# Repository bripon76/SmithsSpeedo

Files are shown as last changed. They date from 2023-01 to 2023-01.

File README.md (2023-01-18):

# SmithsSpeedo
 DIY Speedo Conversation from mechanical to electical

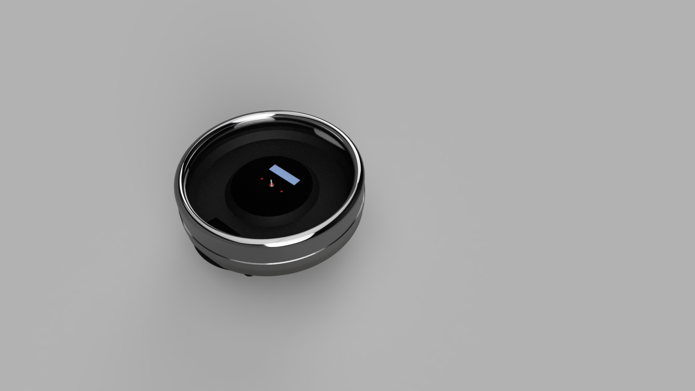
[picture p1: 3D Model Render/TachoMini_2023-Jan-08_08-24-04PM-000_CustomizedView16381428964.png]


# ToDo

- Control and order Top PCB
- Complete, control and order Bottom PCB
- modify Atmel Code for speaking with ESP32 Code

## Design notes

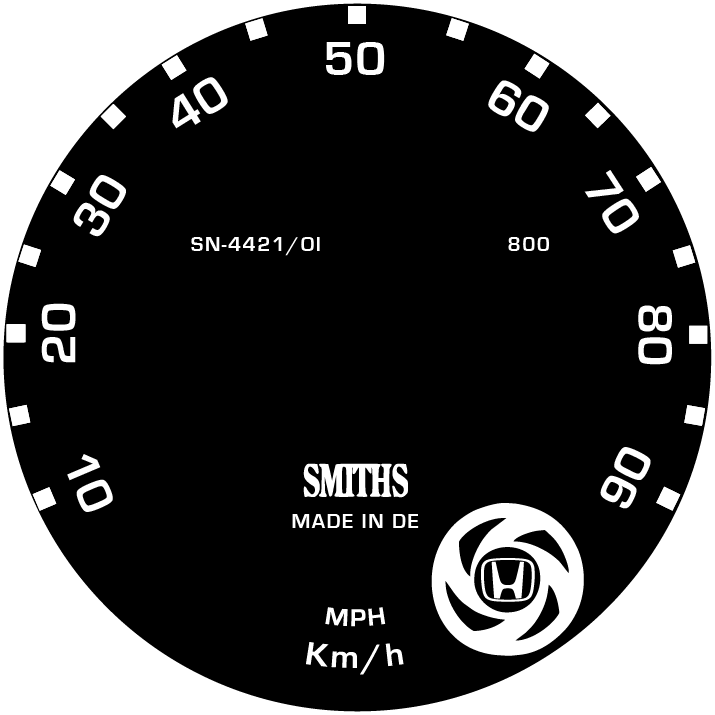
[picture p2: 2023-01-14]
Tachoscheiben/Tachoscheibe HondaMini.png

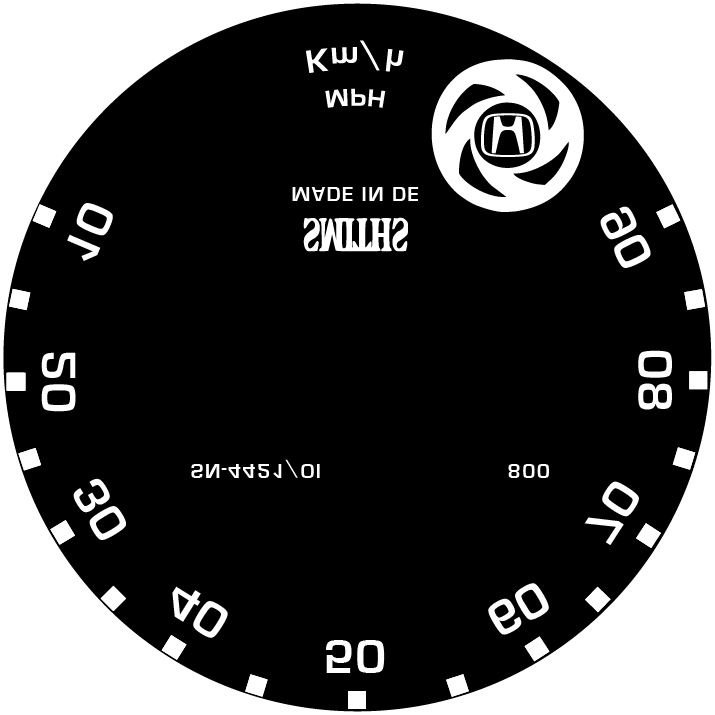
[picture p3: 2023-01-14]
Tachoscheiben/Tachoscheibe HondaMini_flipped.png

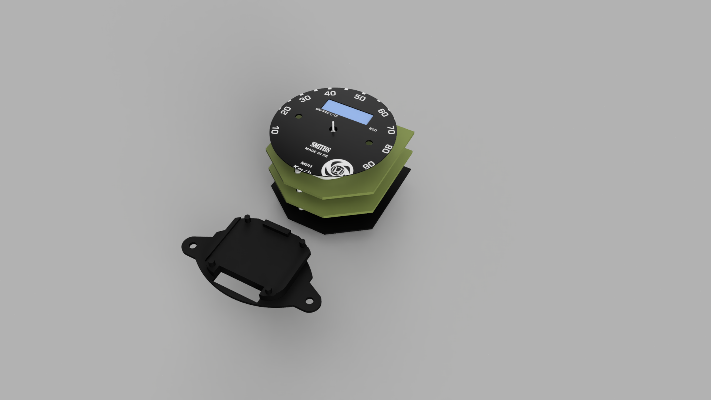
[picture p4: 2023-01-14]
3D Model Render/TachoMini_2022-Apr-28_12-24-32PM-000_CustomizedView3400404055.png

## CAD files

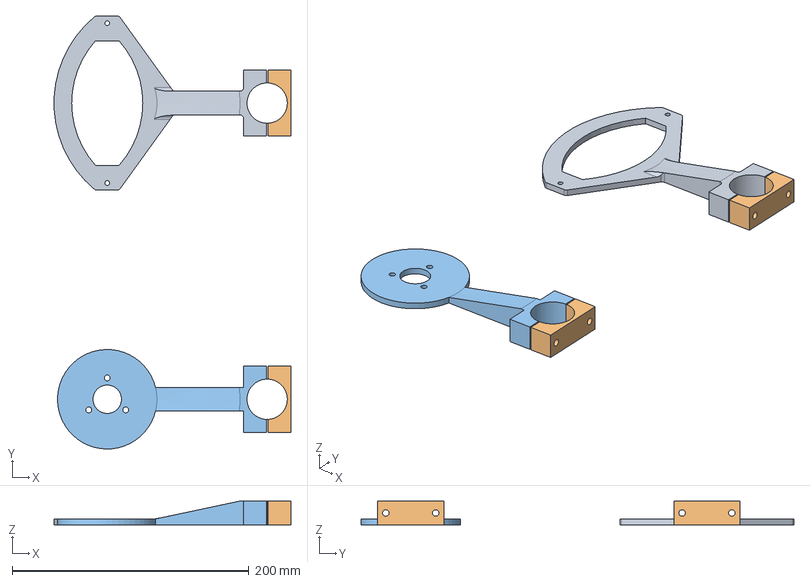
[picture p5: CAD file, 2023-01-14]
3D Model Render/TempHalter v3.step
199.8 x 365.5 x 20.0 mm
Halter Raingauge
Klammer Raingauge
Halter TEMP/HUM
Klammer Tem/HUM

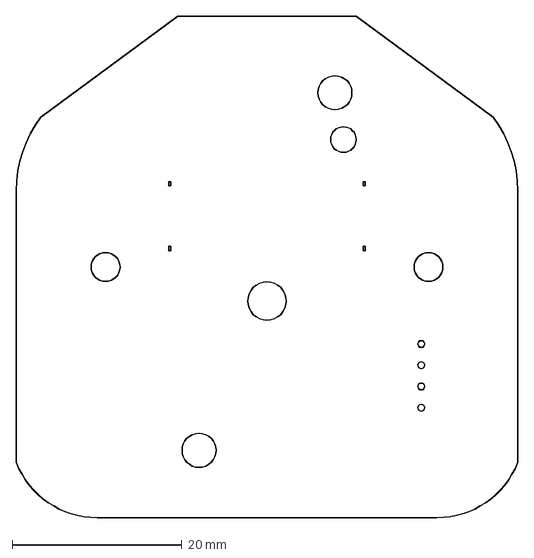
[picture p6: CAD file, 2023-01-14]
PCB Cut.dxf
59.0 x 59.0 mm

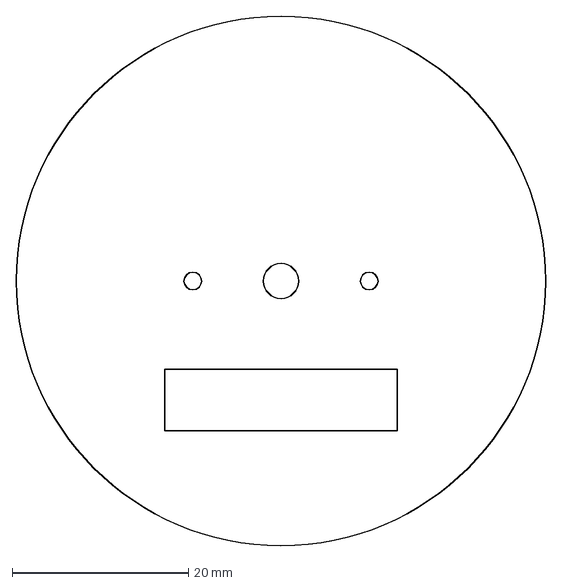
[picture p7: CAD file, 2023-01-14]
PCBs/Tacho Blende/Blende PCB.dxf
60.0 x 60.0 mm

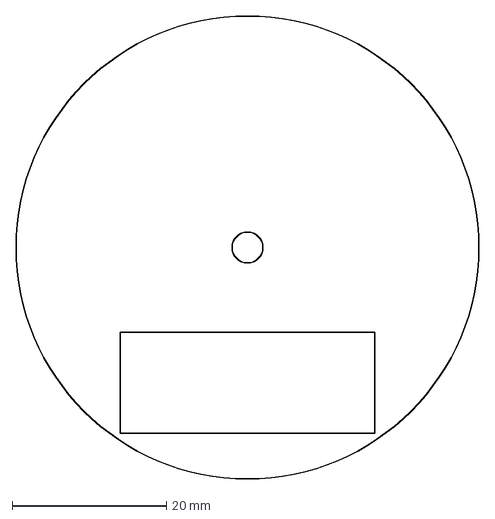
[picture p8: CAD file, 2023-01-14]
Tachoscheiben/Tachoscheibe.dxf
60.0 x 60.0 mm

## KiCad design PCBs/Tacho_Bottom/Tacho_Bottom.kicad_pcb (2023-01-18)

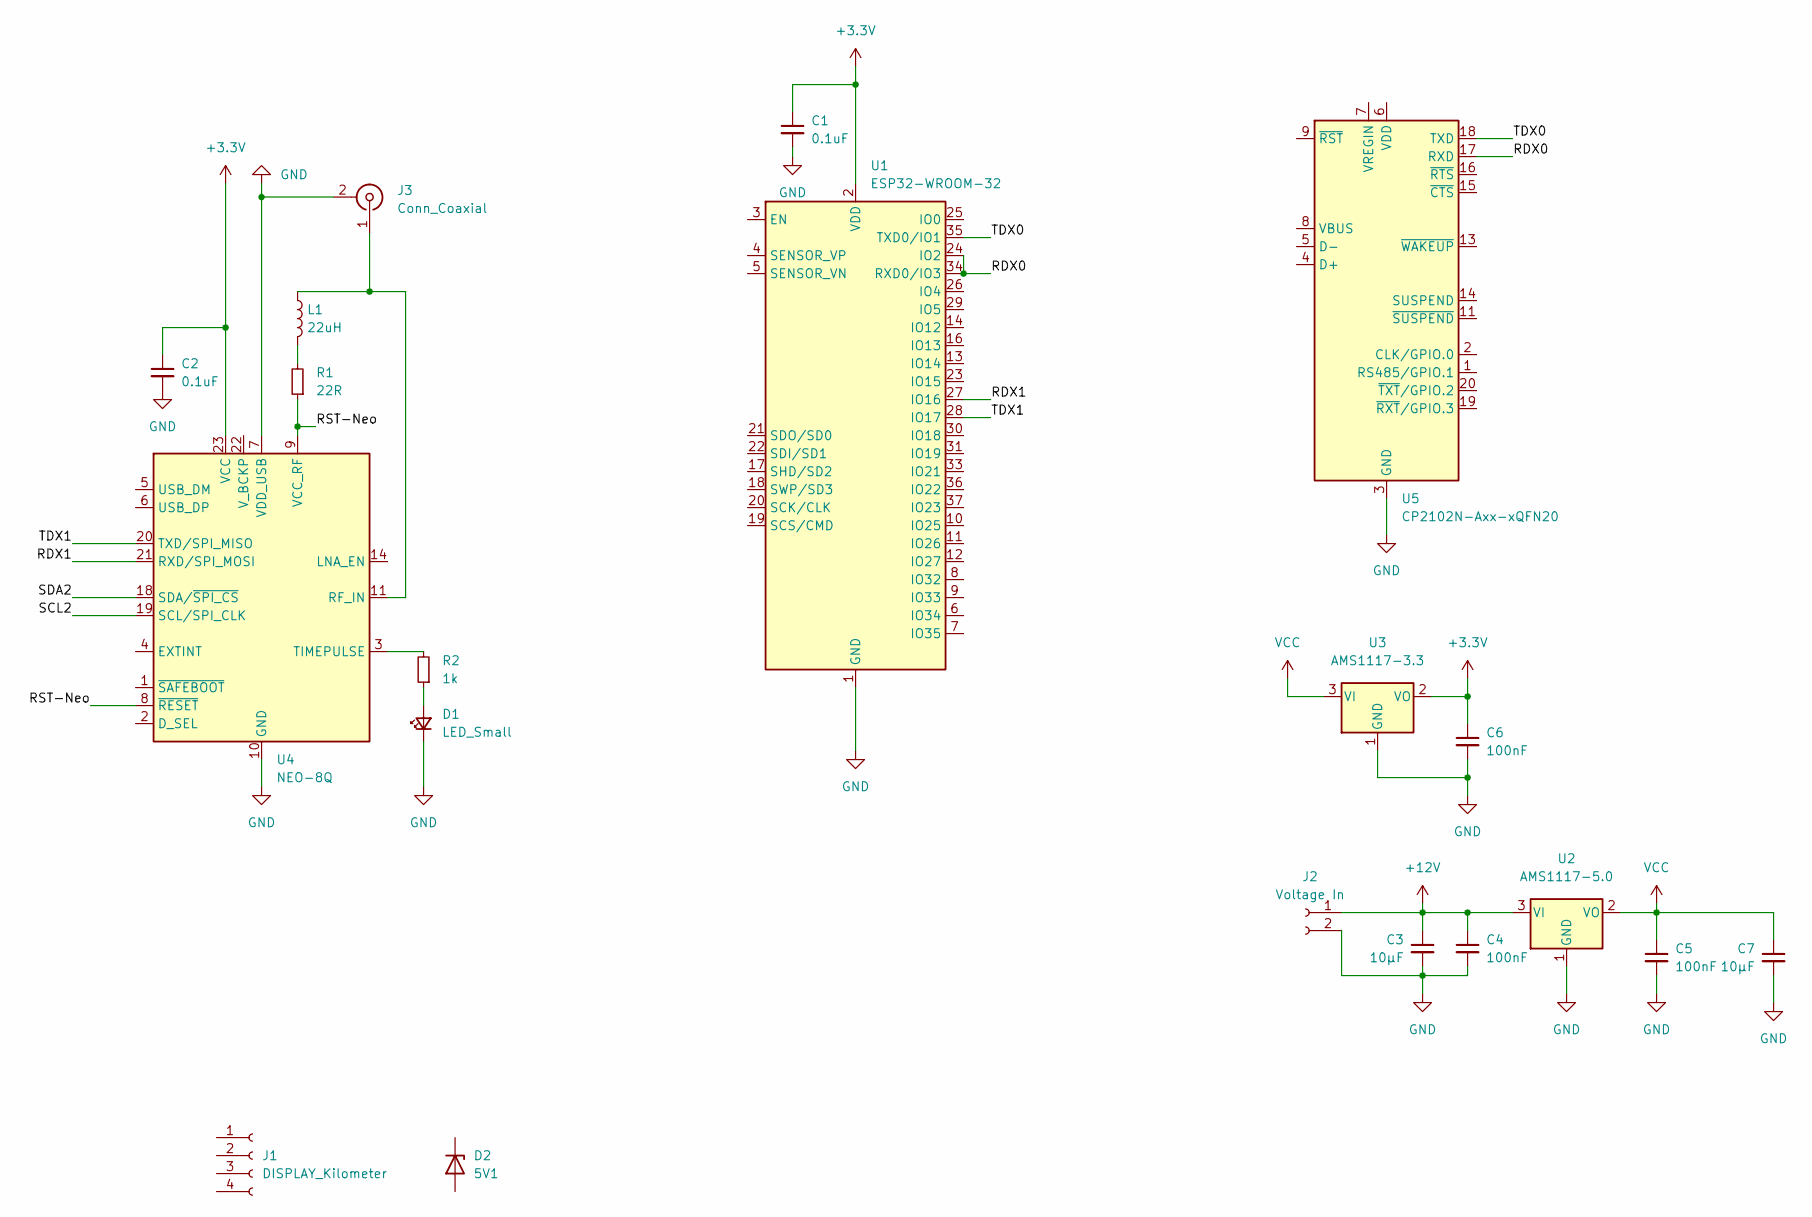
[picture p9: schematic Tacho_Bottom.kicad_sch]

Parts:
C1, C2: 0.1uF; C_0603_1608Metric_Pad1.08x0.95mm_HandSolder
C3, C7: 10µF; C_0805_2012Metric_Pad1.18x1.45mm_HandSolder
C4, C5, C6: 100nF; C_0603_1608Metric_Pad1.08x0.95mm_HandSolder
D1: LED_Small; LED_1206_3216Metric_Pad1.42x1.75mm_HandSolder
D2: 5V1; D_SOD-123
J1: DISPLAY_Kilometer; PinHeader_1x04_P2.54mm_Vertical
J2: Voltage In; SolderWire-0.5sqmm_1x02_P4.8mm_D0.9mm_OD2.3mm
J3: Conn_Coaxial; U.FL_Molex_MCRF_73412-0110_Vertical
L1: 22uH; L_12x12mm_H8mm
R1: 22R; R_0603_1608Metric_Pad0.98x0.95mm_HandSolder
R2: 1k; R_0603_1608Metric_Pad0.98x0.95mm_HandSolder
U1: ESP32-WROOM-32
U2: AMS1117-5.0; SOT-223-3_TabPin2
U3: AMS1117-3.3; SOT-223-3_TabPin2
U4: NEO-8Q; ublox_NEO
U5: CP2102N-Axx-xQFN20; SiliconLabs_QFN-20-1EP_3x3mm_P0.5mm

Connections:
+3.3V: C1.1, C2.1, C6.1, U1.2 (VDD), U3.2 (VO), U4.23 (VCC)
+12V: C3.1, C4.1, J2.1, U2.3 (VI)
/RDX0: U1.24 (IO2), U1.34 (RXD0/IO3), U5.17 (RXD)
/RDX1: U1.27 (IO16), U4.21 (RXD/SPI_MOSI)
/RST-Neo: R1.1, U4.8 (~RESET), U4.9 (VCC_RF)
/SCL2: U4.19 (SCL/SPI_CLK)
/SDA2: U4.18 (SDA/~SPI_CS)
/TDX0: U1.35 (TXD0/IO1), U5.18 (TXD)
/TDX1: U1.28 (IO17), U4.20 (TXD/SPI_MISO)
GND: C1.2, C2.2, C3.2, C4.2, C5.2, C6.2, C7.2, D1.1 (K), J2.2, J3.2 (Ext), U1.1 (GND), U1.15 (GND), U1.38 (GND), U1.39 (GND), U2.1 (GND), U3.1 (GND), U4.7 (VDD_USB), U4.10 (GND), U4.12 (GND), U4.13 (GND), U4.24 (GND), U5.3 (GND), U5.12 (GND), U5.21 (GND)
unnamed: D1.2 (A), R2.1
unnamed: J3.1 (In), L1.1, U4.11 (RF_IN)
unnamed: L1.2, R1.2
unnamed: R2.2, U4.3 (TIMEPULSE)
VCC: C5.1, C7.1, U2.2 (VO), U3.3 (VI)

Board: 2 copper layers, 19 parts (2 on the bottom side), 12 nets, no tracks yet.

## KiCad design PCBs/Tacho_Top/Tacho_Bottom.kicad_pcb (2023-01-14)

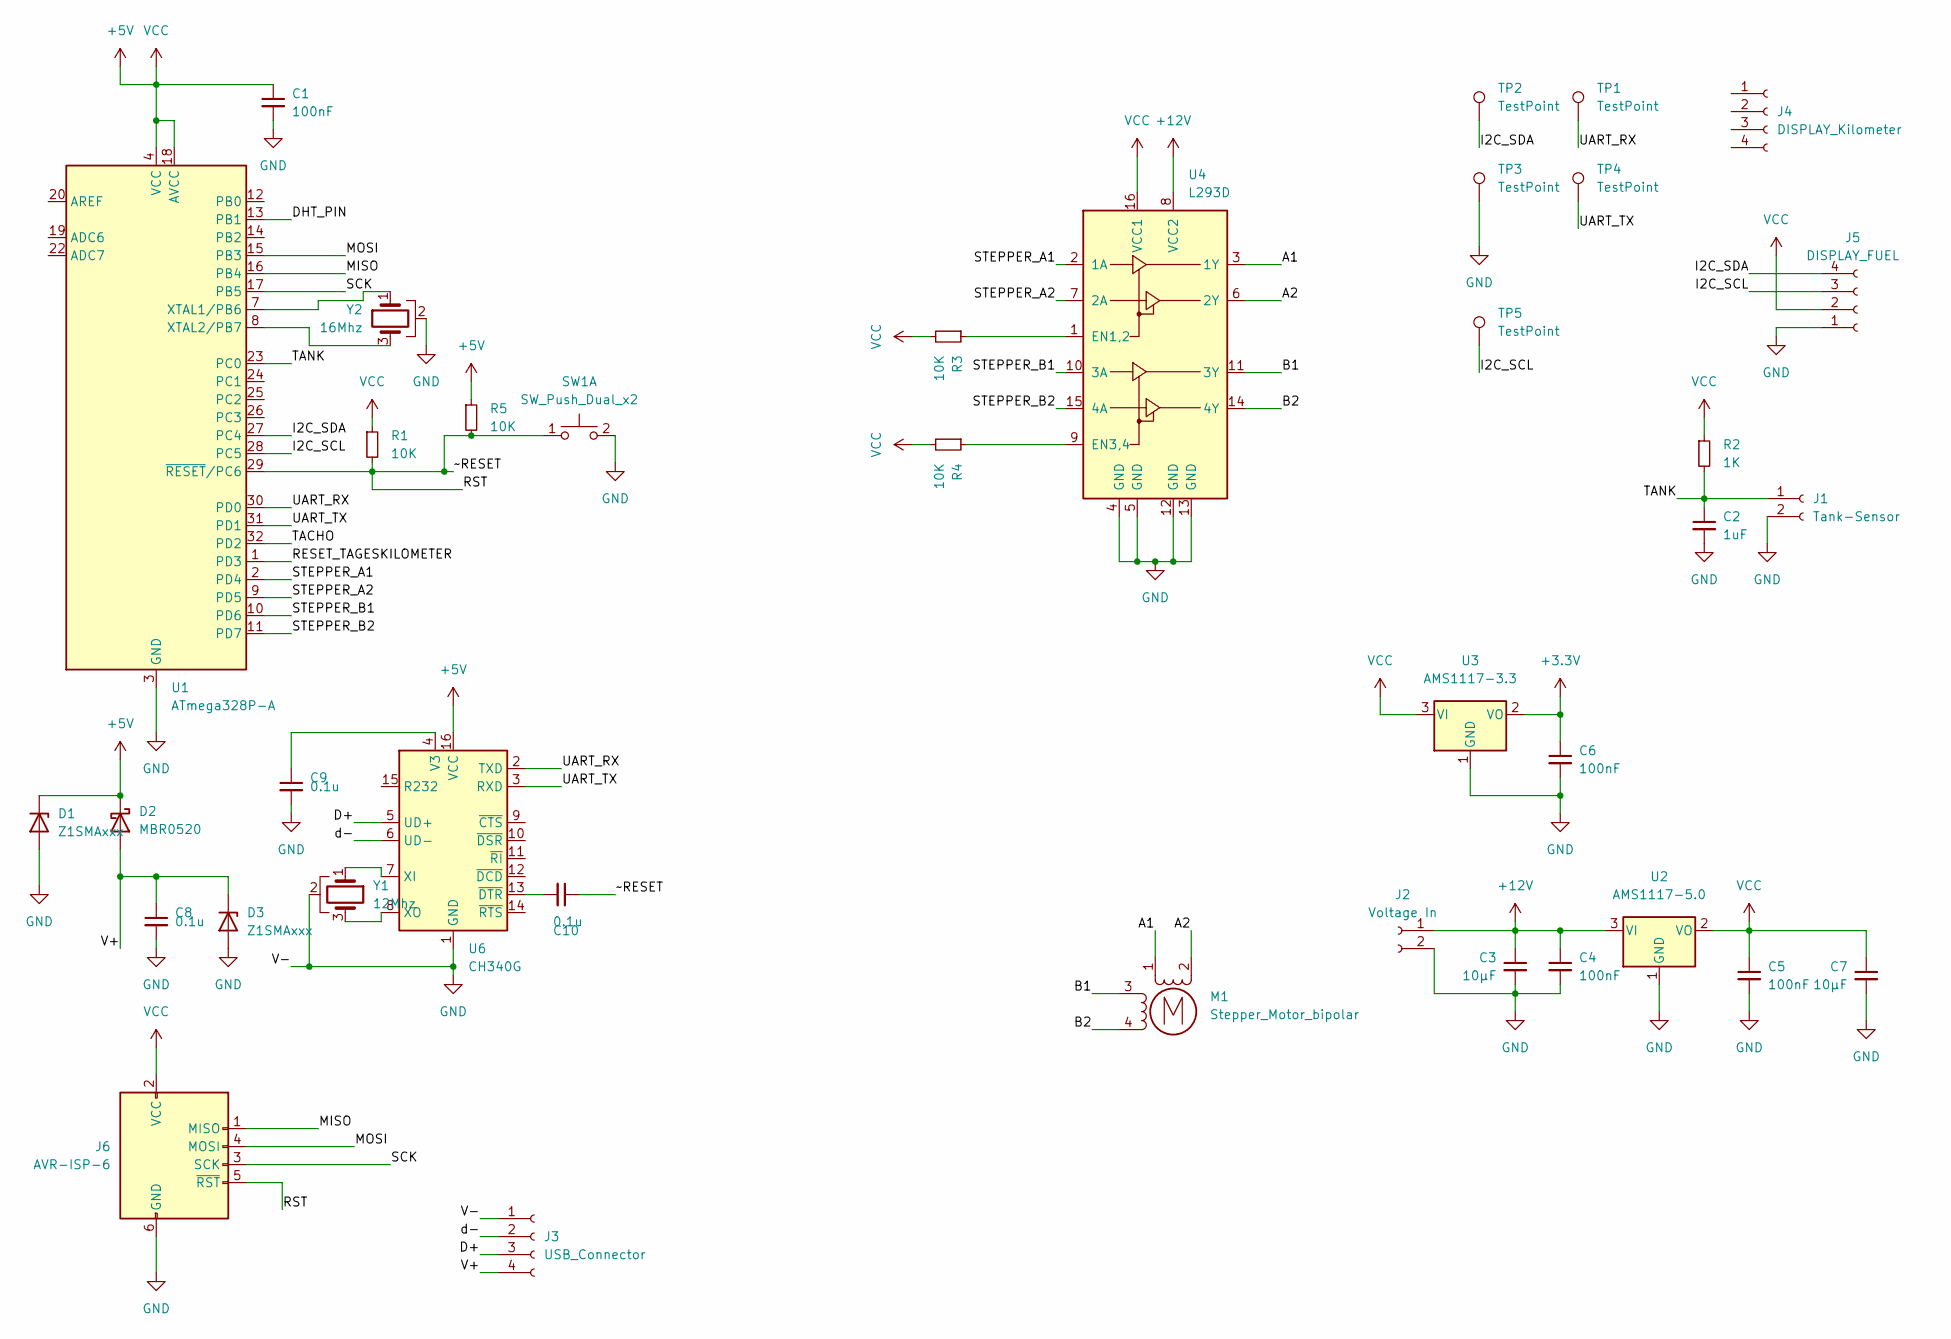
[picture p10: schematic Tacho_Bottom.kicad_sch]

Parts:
C1, C4, C5, C6: 100nF; C_0603_1608Metric_Pad1.08x0.95mm_HandSolder
C2: 1uF; R_0603_1608Metric_Pad0.98x0.95mm_HandSolder
C3, C7: 10µF; C_0805_2012Metric_Pad1.18x1.45mm_HandSolder
C8, C9, C10: 0.1u; R_0603_1608Metric_Pad0.98x0.95mm_HandSolder
D1, D3: Z1SMAxxx; D_SMA
D2: MBR0520; D_SOD-123
J1: Tank-Sensor; SolderWire-0.1sqmm_1x02_P3.6mm_D0.4mm_OD1mm
J2: Voltage In; SolderWire-0.5sqmm_1x02_P4.8mm_D0.9mm_OD2.3mm
J3: USB_Connector; PinHeader_1x04_P2.54mm_Vertical
J4: DISPLAY_Kilometer; PinHeader_1x04_P2.54mm_Vertical
J5: DISPLAY_FUEL; SolderWire-0.1sqmm_1x04_P3.6mm_D0.4mm_OD1mm
J6: AVR-ISP-6; PinHeader_2x03_P2.54mm_Vertical
M1: Stepper_Motor_bipolar; X27-168
R1, R3, R4, R5: 10K; R_0603_1608Metric_Pad0.98x0.95mm_HandSolder
R2: 1K; R_0603_1608Metric_Pad0.98x0.95mm_HandSolder
SW1: SW_Push_Dual_x2
TP1, TP2, TP3, TP4, TP5: TestPoint; TestPoint_Pad_D2.0mm
U1: ATmega328P-A; TQFP-32_7x7mm_P0.8mm
U2: AMS1117-5.0; SOT-223-3_TabPin2
U3: AMS1117-3.3; SOT-223-3_TabPin2
U4: L293D; DIP-16_W7.62mm
U6: CH340G; SOIC-16_3.9x9.9mm_P1.27mm
Y1: 12Mhz
Y2: 16Mhz

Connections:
+3.3V: C6.1, U3.2 (VO)
+5V: C1.1, C5.1, C7.1, D1.1 (K), D2.1 (K), J5.2, J6.2 (VCC), R1.1, R2.1, R3.2, R4.2, R5.1, U1.4 (VCC), U1.6 (VCC), U1.18 (AVCC), U2.2 (VO), U3.3 (VI), U4.16 (VCC1), U6.16 (VCC)
+12V: C3.1, C4.1, J2.1, U2.3 (VI), U4.8 (VCC2)
/A1: M1.1, U4.3 (1Y)
/A2: M1.2 (-), U4.6 (2Y)
/B1: M1.3, U4.11 (3Y)
/B2: M1.4, U4.14 (4Y)
/D+: J3.3, U6.5 (UD+)
/DHT_PIN: U1.13 (PB1)
/I2C_SCL: J5.3, TP5.1, U1.28 (PC5)
/I2C_SDA: J5.4, TP2.1, U1.27 (PC4)
/MISO: J6.1 (MISO), U1.16 (PB4)
/MOSI: J6.4 (MOSI), U1.15 (PB3)
/RESET_TAGESKILOMETER: U1.1 (PD3)
/RST: C10.1, J6.5 (~RST), R1.2, R5.2, SW1.1 (C), U1.29 (~RESET/PC6)
/SCK: J6.3 (SCK), U1.17 (PB5)
/STEPPER_A1: U1.2 (PD4), U4.2 (1A)
/STEPPER_A2: U1.9 (PD5), U4.7 (2A)
/STEPPER_B1: U1.10 (PD6), U4.10 (3A)
/STEPPER_B2: U1.11 (PD7), U4.15 (4A)
/TACHO: U1.32 (PD2)
/TANK: C2.1, J1.1, R2.2, U1.23 (PC0)
/UART_RX: TP1.1, U1.30 (PD0), U6.2 (TXD)
/UART_TX: TP4.1, U1.31 (PD1), U6.3 (RXD)
/V+: C8.1, D2.2 (A), D3.1 (K), J3.4
/d-: J3.2, U6.6 (UD-)
GND: C1.2, C2.2, C3.2, C4.2, C5.2, C6.2, C7.2, C8.2, C9.2, D1.2 (A), D3.2 (A), J1.2, J2.2, J3.1, J5.1, J6.6 (GND), SW1.2 (D), TP3.1, U1.3 (GND), U1.5 (GND), U1.21 (GND), U2.1 (GND), U3.1 (GND), U4.4 (GND), U4.5 (GND), U4.12 (GND), U4.13 (GND), U6.1 (GND), Y1.2, Y2.2
unnamed: C9.1, U6.4 (V3)
unnamed: C10.2, U6.13 (~DTR)
unnamed: R3.1, U4.1 (EN1,2)
unnamed: R4.1, U4.9 (EN3,4)
unnamed: U1.7 (XTAL1/PB6), Y2.1
unnamed: U1.8 (XTAL2/PB7), Y2.3
unnamed: U6.7 (XI), Y1.1
unnamed: U6.8 (XO), Y1.3

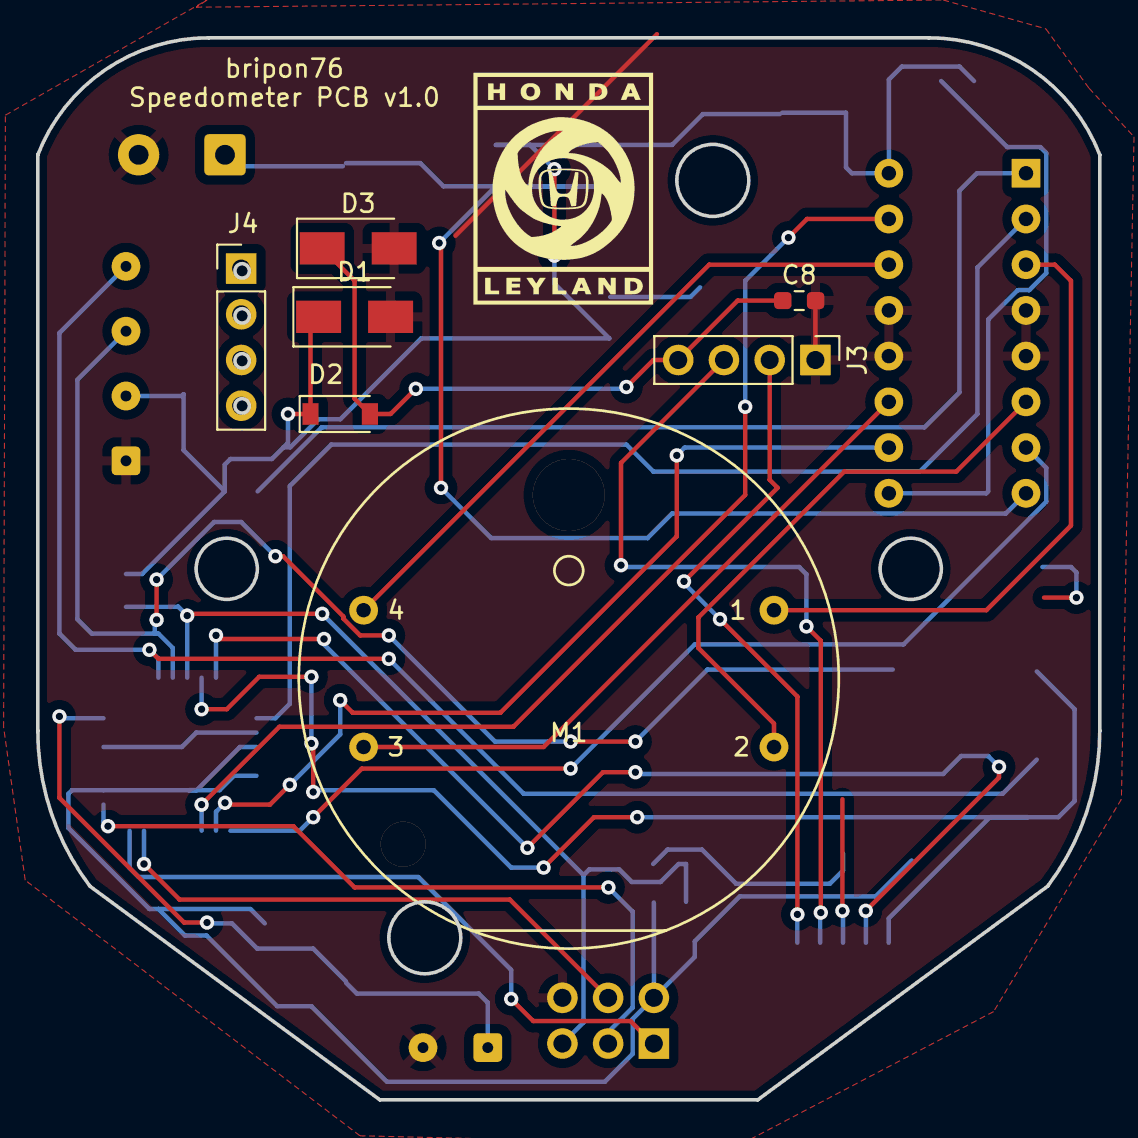
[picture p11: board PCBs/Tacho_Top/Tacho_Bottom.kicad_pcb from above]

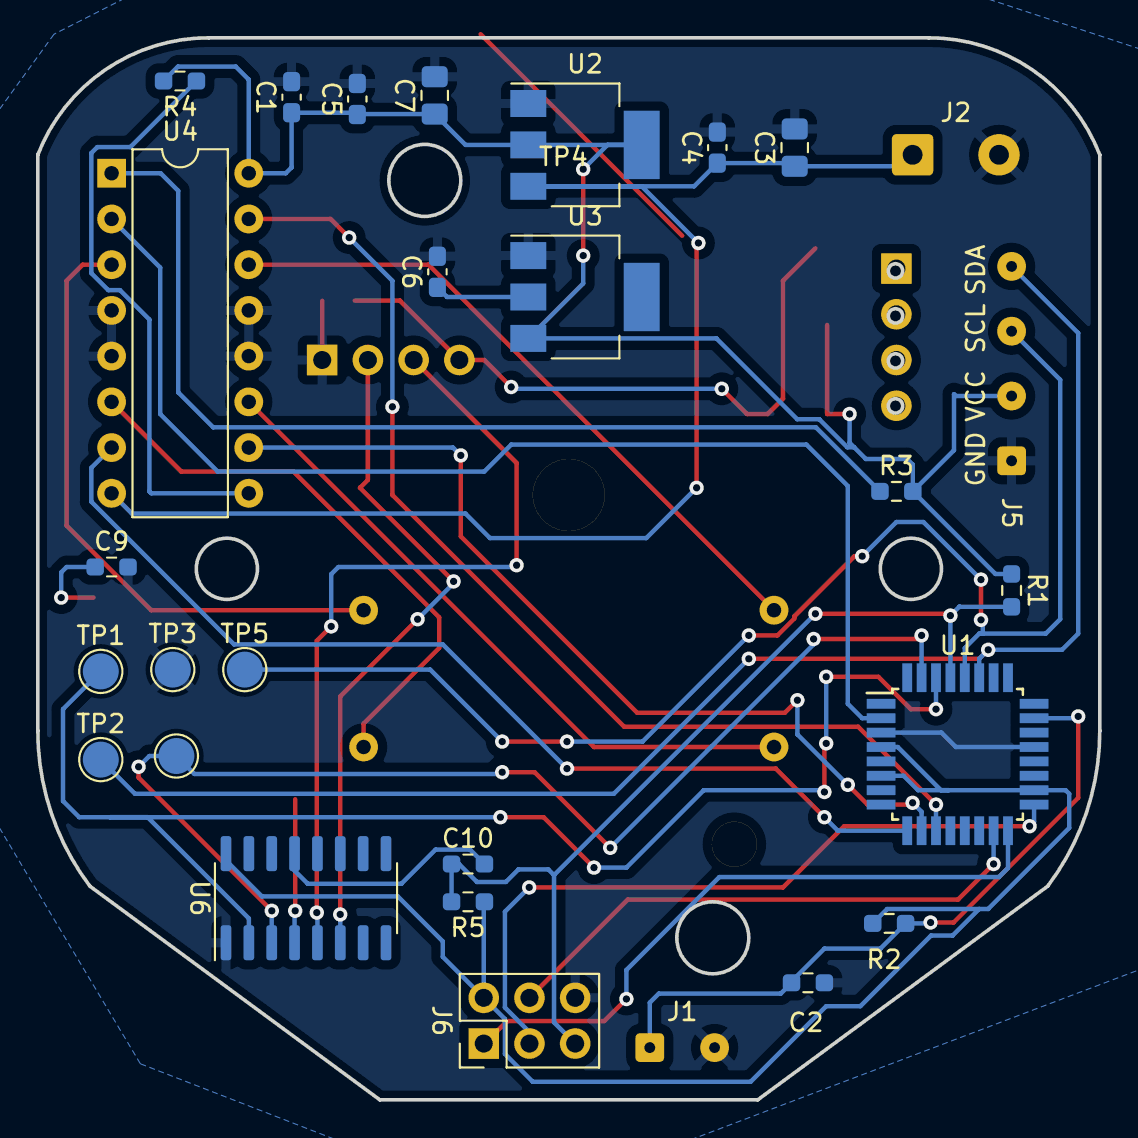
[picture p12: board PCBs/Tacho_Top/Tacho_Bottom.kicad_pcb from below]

Board: 2 copper layers, 59.0 x 59.0 mm, 35 parts (28 on the bottom side), 28 nets.

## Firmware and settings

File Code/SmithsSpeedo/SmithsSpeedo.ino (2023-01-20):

//To Do:
//Kilometer alle 10 min. speichern (optional)
//Tageskilometerzähler (Differenz zwischen realem Kilometerzähler und letztem Reset-Kilometerstand)

#include <EEPROM.h>
#include <Arduino.h>
#include <U8g2lib.h>

#ifdef U8X8_HAVE_HW_SPI
#include <SPI.h>
#endif
#ifdef U8X8_HAVE_HW_I2C
#include <Wire.h>
#endif

//Tacho-Stepper Motor
#define STEPS_KMH_140 690.0 /*Steps per 140 km/h*/
#define STEPS_MAXRANGE 850 /* Rechte Seite FUEL Ausschnitt*/
#include <SwitecX25.h>

//SoftwareSerial
#include <SoftwareSerial.h>
SoftwareSerial mySerial(2, 3); // RX, TX

// standard X25.168 range 315 degrees at 1/3 degree steps
#define STEPS (315*3)
// For motors connected to digital pins 4,5,6,7
SwitecX25 motor1(STEPS, 4, 5, 6, 7);

U8G2_SH1106_128X64_NONAME_1_HW_I2C fuel(U8G2_R2, /* reset=*/ U8X8_PIN_NONE); //Grosses Display (FUEL) X:10..117 Y:17..44
U8G2_SSD1306_128X32_UNIVISION_1_HW_I2C kilometer(U8G2_R0, /* reset=*/ U8X8_PIN_NONE);  //kleines Display (Kilometerstand)

/********* Kilometerzähler ***********/
#define ORIGINAL_KILOMETERS 1503880
unsigned long totalKilometers = 0; //; //x10
unsigned long totalPulses = 0;
char kilometerBuffer[10]; //Textpuffer für Kilometerdisplay
unsigned long nextKilometerMillis = 0;
int kilometerTimeout = 0; //Zeitmessung für Kilometer speichern im Stand
#define KILOMETER_TIMEOUT_SECONDS 10 /*Timeout in Sekunden*/
int tagesKilometerReset=0; //Tageskilometerzähler letzter Reset-Stand
char tagesKilometerBuffer[8]={};//Textpuffer für Tageskilometerdisplay


unsigned long displayKilometers=0; //Zwischenspeicher für Displays (Berechnung Kilometerstand aus Pulsen)

/********* Geschwindigkeitsmessung ***********/
volatile uint16_t timerSteps = 0;

#define STEPS_REV 5 /*Steps/rev*/
#define CIRCUMFERENCE 1.531 /*m*/
uint32_t nextSampleMillis = 0;

/*********Für motorische analoge Anzeige******/
double maxSpeed = 160;
double kmh = 0;
double lastKmh = 0;
struct stuetzstellen {
  int skala;
  int steps;
};

struct stuetzstelleEintrag {
  int links;
  int rechts;
};

int skalaListLength = 10; //10 Einträge
stuetzstellen skalaWerte[] = {
  {.skala = 0, .steps = 0},
  {.skala = 20, .steps = 50},
  {.skala = 40, .steps = 160},
  {.skala = 60, .steps = 268},
  {.skala = 80, .steps = 375},
  {.skala = 100, .steps = 478},
  {.skala = 120, .steps = 582},
  {.skala = 140, .steps = 683},
  {.skala = 150, .steps = 743},
  {.skala = 160, .steps = 815}
};


//Argumente: xn=km/h-Wert
stuetzstelleEintrag findListEntry(double xn, stuetzstellen* stuetzstellenliste, uint8_t listLength) {
  stuetzstelleEintrag returnStruct;
  int returnValue = 0;
  //Rechte Stützstelle finden
  for (int i = 0; i < listLength; i++) {
    returnValue = i;
    if (stuetzstellenliste[i].skala >= xn) break;
  }
  returnStruct.rechts = returnValue;

  returnValue = listLength - 1;
  //Linke Stützstelle finden
  for (int i = (listLength - 1); i >= 0; i--) {
    returnValue = i;
    if (stuetzstellenliste[i].skala <= xn) break;
  }
  returnStruct.links = returnValue;
  return returnStruct;
}

int linearInterpolation(double xn, double x1, int y1, double x2, int y2) {
  int yn = y1 + ((y2 - y1) / (x2 - x1)) * (xn - x1);
  return yn;
}

/*********Ende motorische analoge Anzeige******/


/****** Tanknadel *******/
int fuelListLength = 7; //10 Einträge
//steps=liter, skala=ADC Value
stuetzstellen fuelWerte[] = {
  {.skala = 293, .steps = 20},
  {.skala = 306, .steps = 17},
  {.skala = 333, .steps = 13},
  {.skala = 448, .steps = 8},
  {.skala = 591, .steps = 5},
  {.skala = 721, .steps = 3},
  {.skala = 968, .steps = 0}
};

double maxLiters = 20;
double minAngle = (70.0 / 180.0) * 3.14159; //Rechter Anschlag
double maxAngle = (108.0 / 180.0) * 3.14159; //Linker Anschlag
double needleAngle = 0;
uint32_t nextFuelMillis = 0; //Millisekunden, bis Display refresh bekommen soll
uint32_t nextNeedleMillis = 0; //Millisekunden, bis Nadel refresh bekommen soll
double lastneedleAngle = maxAngle; //Für Filterfunktion (Start bei maxAngle=Start bei Minimum)

int xShift = 63, yShift = -140;
int r1 = 151;
int r2 = 171;
int x1, y1, x2, y2;
/****** Ende Tanknadel *******/

/******** Temperatur/Feuchtesensor******/

// Written by ladyada, public domain

// REQUIRES the following Arduino libraries:
// - DHT Sensor Library: https://github.com/adafruit/DHT-sensor-library
// - Adafruit Unified Sensor Lib: https://github.com/adafruit/Adafruit_Sensor

#include "DHT.h"
#define DHTPIN 9     // Digital pin connected to the DHT sensor
#define DHTTYPE DHT22   // DHT 22  (AM2302), AM2321
#define DHT_VCC_PIN 8
#define DHT_GND_PIN 10
uint32_t nextTemperatureMillis = 0;
float temperature, humidity;
DHT dht(DHTPIN, DHTTYPE);


void setup() {
  Serial.begin(9600);

  //Softwareserial
  // set the data rate for the SoftwareSerial port
  mySerial.begin(9600);
  mySerial.println("Hello, world?");

  //Kilometerstand aus EEPROM holen
  totalKilometers = readEepromWL24();
  tagesKilometerReset = readEeprom24(256); //256...258

  
  Serial.println(totalKilometers);

  //Timer1 Setup für Tachogeber
  TIMSK1 = (1 << TOIE1); //Enable Timer Overflow Interrupt
  TCCR1A = 0; //Normal Mode, no pins connected
  TCCR1B = 0 ; //Stop Timer1, is activated by first pulse on Int0
  TCNT1 = 0;
  //TCCR1B = (1 << CS12); //Pre-Scaler 256 --> 16 MHz/256=62.5 kHz (0.95 Hz min)
  //Timer is configured with 16 µs--> resolution.

  //Interrupt Pin setup
  attachInterrupt(digitalPinToInterrupt(2), freqMeasure, RISING);


  //Initialize DHT Temperature Sensor
  //GND and VCC Pins
  
  pinMode(DHT_VCC_PIN, OUTPUT);
  pinMode(DHT_GND_PIN, OUTPUT);
  digitalWrite(DHT_GND_PIN, LOW);
  digitalWrite(DHT_VCC_PIN, HIGH);
  dht.begin();
  //Dummy reading
  double dummy = dht.readTemperature();
  
  // run the motor against the stops
  motor1.zero();
  // start moving towards the center of the range
  motor1.setPosition(0);


  // put your setup code here, to run once:
  fuel.setI2CAddress(0x7A);
  fuel.begin();
  kilometer.begin();
  fuel.firstPage();
  do {

    fuel.setFont(u8g2_font_logisoso16_tr);
    fuel.setFontPosTop();
    fuel.drawStr(37, 22, "SMITHS");
    fuel.drawStr(37, 40, "Digital");
  } while ( fuel.nextPage() );



  kilometerText(totalKilometers);
  drawKilometer();

  //ist EEPROM fabrikneu? Kilometerstand reinschreiben
  if (totalKilometers == 0x00FFFFFF) {
    writeEepromWL24(ORIGINAL_KILOMETERS);
    totalKilometers = ORIGINAL_KILOMETERS;
  }

  motor1.setPosition(STEPS_MAXRANGE);
  motor1.updateBlocking();
  motor1.setPosition(0);
  motor1.updateBlocking();

  //Serial.println("unfiltered\tfiltered");
}

uint32_t globalMillis = 0;

void loop() {



  globalMillis = millis();
  // Geschwindigkeitsmessung
  if (globalMillis > nextSampleMillis) {
    double tempKmh = 0;
    nextSampleMillis = globalMillis + 100;
    if (timerSteps != 0) tempKmh = (3.6 * (CIRCUMFERENCE / STEPS_REV) / (0.000016 * (double)timerSteps));
    else tempKmh = 0;
    kmh = (0.9 * lastKmh) + (0.1 * tempKmh); //Filterfunktion
    //Serial.print(tempKmh); Serial.print('\t'); Serial.println(kmh);


    lastKmh = kmh;

    //Serial.print(lastKmh);

    int nextPos = kmh;
    if (nextPos > maxSpeed)nextPos = maxSpeed;
    if (nextPos < 0)nextPos = 0;
    //Tachonadel
    stuetzstelleEintrag berechnung = findListEntry(nextPos, skalaWerte, skalaListLength);
    int yn;
    if (berechnung.links == berechnung.rechts) yn = skalaWerte[berechnung.links].steps;
    else {
      yn = linearInterpolation(nextPos, skalaWerte[berechnung.links].skala, skalaWerte[berechnung.links].steps,
                               skalaWerte[berechnung.rechts].skala, skalaWerte[berechnung.rechts].steps);
    }
    motor1.setPosition(yn);
  }



  // Kilometerstand
  if (globalMillis > nextKilometerMillis) {

    nextKilometerMillis = globalMillis + 1400;

    //aus totalPulses Kilometerstand x10 berechnen
    displayKilometers = totalKilometers + ((totalPulses / STEPS_REV) * CIRCUMFERENCE) / 100;
    kilometerText(displayKilometers);
    drawKilometer();
    //Serial.print(displayKilometers);
    }



  
  // Wait a few seconds between measurements.
  if (globalMillis > nextTemperatureMillis) {
    nextTemperatureMillis = globalMillis + 10000;
    //humidity = dht.readHumidity();
    // Read temperature as Celsius (the default)
    temperature = dht.readTemperature();
  }

 
  // put your main code here, to run repeatedly:
  if (globalMillis > nextNeedleMillis) {
    nextNeedleMillis = globalMillis + 1000;
    int fuelAnalog = analogRead(0);
    double liters;
    stuetzstelleEintrag berechnung = findListEntry(fuelAnalog, fuelWerte, fuelListLength);
    if (berechnung.links == berechnung.rechts) liters = fuelWerte[berechnung.links].steps;
    else {
      liters = linearInterpolation(fuelAnalog, fuelWerte[berechnung.links].skala, fuelWerte[berechnung.links].steps,
                                   fuelWerte[berechnung.rechts].skala, fuelWerte[berechnung.rechts].steps);
    }

    double newAngle = maxAngle - (((maxAngle - minAngle) / maxLiters) * liters);
    needleAngle = (newAngle * 0.3) + (lastneedleAngle * 0.7);
    lastneedleAngle = needleAngle;
    if (needleAngle < minAngle) needleAngle = minAngle;
    if (needleAngle >= maxAngle) needleAngle = maxAngle;
    // put your main code here, to run repeatedly:
    x1 = (cos(needleAngle) * r1) + xShift;
    y1 = (sin(needleAngle) * r1) + yShift;
    x2 = (cos(needleAngle) * r2) + xShift;
    y2 = (sin(needleAngle) * r2) + yShift;
  }


  //Tanknadel Display zeichnen und Kilometer speichern
  if (globalMillis > nextFuelMillis) {
    nextFuelMillis = globalMillis + 1000;
    //Hier wird ein Sekundentakt abgegriffen, um die Zeit im Stand zu messen (für Kilometer im EEPROM speichern)
    if (kmh == 0 && kilometerTimeout) {
      if (kilometerTimeout <= KILOMETER_TIMEOUT_SECONDS)
        kilometerTimeout++;
    } else { //if kmh !=0
      kilometerTimeout = 0;
    }

    //Kilometer speichern wenn kilometerTimeout Sollwert erreicht hat
    if(kilometerTimeout==KILOMETER_TIMEOUT_SECONDS) {
      writeEepromWL24(displayKilometers);
    }

    fuel.firstPage();
    do {
      fuel.setFontPosTop();

      //Wenn Tacho>MaxSpeed, dann in großer Schrift km/h darstellen

      if (kmh > maxSpeed) {
        fuel.setFont(u8g2_font_logisoso32_tn);
        fuel.setCursor(18, 18);
        fuel.print(kmh, 1);
      }

      //Anzeige der Tanknadel und der Temperatur etc.
      else {
        fuel.setFont(u8g2_font_logisoso16_tr);
        fuel.drawStr(10, 22, "E");
        fuel.drawStr(50, 26, "1/2");
        fuel.drawStr(106, 22, "F");
        fuel.drawLine(x1, y1, x2, y2); //Nadel
        fuel.drawLine(x1 + 1, y1, x2 + 1, y2); //Nadel
        fuel.drawLine(x1 - 1, y1, x2 - 1, y2); //Nadel

        
        fuel.setCursor(10, 45);
        fuel.print((int)temperature);
        fuel.print("*C");

        //Tageskilometerzähler
        fuel.setCursor(70, 45);
        tagesKilometerText(displayKilometers-tagesKilometerReset);
        fuel.print(tagesKilometerBuffer);
        //Serial.print(tagesKilometerBuffer);
      }
    } while ( fuel.nextPage());
  }

  // the motor only moves when you call update
  motor1.update();

espsenddata();


}

//Kilometerstand speichern
void writeEepromWL24(uint32_t myvalue) {
  //Cap value. at 24 Bits (3 Bytes)
  myvalue &= 0x00FFFFFF;
  //Find address for Low Byte
  uint16_t hiAddr = 255; //Base address
  uint16_t midAddr = hiAddr - 1;
  uint16_t loAddr = ((myvalue & 0x00FF0000) >> 16) % 253;

  //EEPROM.write(addr, val);
  EEPROM.write(hiAddr, ((myvalue & 0x00FF0000) >> 16));
  EEPROM.write(midAddr, ((myvalue & 0x0000FF00) >> 8));
  EEPROM.write(loAddr, (myvalue & 0x000000FF));
}

uint32_t readEepromWL24() {
  //Find address for Low Byte
  uint16_t hiAddr = 255; //Base address
  uint16_t midAddr = hiAddr - 1;
  //value = EEPROM.read(address);
  uint16_t loAddr = EEPROM.read(hiAddr);

  uint32_t myvalue = (EEPROM.read(loAddr) << 0) & 0x000000FF;
  myvalue |= (EEPROM.read(midAddr) << 8) & 0x0000FF00;
  myvalue |= ((uint32_t)loAddr << 16) & 0x00FF0000;
  return myvalue;
}

//Kilometerstand speichern
void writeEeprom24(uint32_t addr, uint32_t myvalue) {
  //Cap value. at 24 Bits (3 Bytes)
  myvalue &= 0x00FFFFFF;
  //Find address for Low Byte
  uint16_t hiAddr = addr+2; //Base address
  uint16_t midAddr = hiAddr - 1;
  uint16_t loAddr = hiAddr - 2;

  //EEPROM.write(addr, val);
  EEPROM.write(hiAddr, ((myvalue & 0x00FF0000) >> 16));
  EEPROM.write(midAddr, ((myvalue & 0x0000FF00) >> 8));
  EEPROM.write(loAddr, (myvalue & 0x000000FF));
}

uint32_t readEeprom24(uint32_t addr) {
  uint16_t hiAddr = addr+2; //Base address
  uint16_t midAddr = hiAddr - 1;
  uint16_t loAddr = hiAddr - 2;

  uint32_t myvalue = (EEPROM.read(loAddr) << 0) & 0x000000FF;
  myvalue |= (EEPROM.read(midAddr) << 8) & 0x0000FF00;
  myvalue |= ((uint32_t)loAddr << 16) & 0x00FF0000;
  return myvalue;
}

//Kilometer auf Kilometerzähler anzeigen
void kilometerText(unsigned long totalKilometers) {
  unsigned int numbers[8] = {};
  numbers[0] = (totalKilometers / 10000000) % 10;
  numbers[1] = (totalKilometers / 1000000) % 10;
  numbers[2] = (totalKilometers / 100000) % 10;
  numbers[3] = (totalKilometers / 10000) % 10;
  numbers[4] = (totalKilometers / 1000) % 10;
  numbers[5] = (totalKilometers / 100) % 10;
  numbers[6] = (totalKilometers / 10) % 10;
  numbers[7] = (totalKilometers) % 10;
  sprintf(kilometerBuffer, "%0u%0u%0u%0u%0u%0u%0u,%0u", numbers[0], numbers[1], numbers[2], numbers[3], numbers[4], numbers[5], numbers[6], numbers[7]);
}

//Tageskilometer auf Fuel-Anzeige anzeigen
void tagesKilometerText(unsigned long totalKilometers) {
  unsigned int numbers[4] = {};
  numbers[0] = (totalKilometers / 1000) % 10;
  numbers[1] = (totalKilometers / 100) % 10;
  numbers[2] = (totalKilometers / 10) % 10;
  numbers[3] = (totalKilometers) % 10;
  sprintf(tagesKilometerBuffer, "%0u%0u%0u,%0u", numbers[0], numbers[1], numbers[2], numbers[3]);
}

void drawKilometer() {
  kilometer.setContrast(0);
  kilometer.firstPage();
  do {
    kilometer.setFont(u8g2_font_logisoso22_tn);
    kilometer.drawStr(0, 28, kilometerBuffer);
  } while ( kilometer.nextPage());
}

//Timer Overflow Interrupt: Disable Timer0 clock, save timerSteps as 0.
ISR (TIMER1_OVF_vect) {
  TCCR1B = 0; //stop Timer1
  timerSteps = 0; //Set 0 timer steps
}

//Pin 2 Interrupt
void freqMeasure() {
  //TCCR1B = 0; //stop Timer1
  timerSteps = TCNT1; //Save Timer1 value
  TCCR1B = (1 << CS12); //Start Timer1
  TCNT1 = 0; //Reset Timer1
  totalPulses++;
}

void espsenddata(){
  #define SEPARATION_CHAR ','
  //ESP Data
  //{"TotalKm":150510,"DayKm":19,"AverageKmh":34,"AverageFuel":5.4,"Fuel":17,"TopSpeed":172}
  mySerial.print("{");
  mySerial.print(F("\"TotalKm\":\"")); mySerial.print(totalKilometers); mySerial.print('\"'); mySerial.print(SEPARATION_CHAR);
  mySerial.print(F("\"DayKm\":\"")); mySerial.print(tagesKilometerBuffer); mySerial.print('\"'); mySerial.print(SEPARATION_CHAR);
  mySerial.print(F("\"AverageKmh\":\"")); mySerial.print("Demo"); mySerial.print('\"'); mySerial.print(SEPARATION_CHAR);
  mySerial.print(F("\"AverageFuel\":\"")); mySerial.print("Demo"); mySerial.print('\"'); mySerial.print(SEPARATION_CHAR);
  mySerial.print(F("\"Fuel\":\"")); mySerial.print("Demo"); mySerial.print('\"'); mySerial.print(SEPARATION_CHAR);
  mySerial.print(F("\"TopSpeed\":\"")); mySerial.print("Demo"); mySerial.print('\"');
  mySerial.print("}");
  //Finally, print a newline.
  mySerial.println();
  
  delay(2000);

}

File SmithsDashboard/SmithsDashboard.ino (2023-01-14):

// Import required libraries
#include "WiFi.h"
#include "AsyncTCP.h"
#include "ESPAsyncWebServer.h"
#include "SPIFFS.h"
#include "FS.h"
#include <ArduinoJson.h>

// Replace with your network credentials
const char* ssid     = "SmithsDash";
const char* password = "";

// Create AsyncWebServer object on port 80
AsyncWebServer server(80);
AsyncWebSocket ws("/ws");

void initWebSocket() {
  ws.onEvent(onEvent);
  server.addHandler(&ws);
}

void onEvent(AsyncWebSocket *server, AsyncWebSocketClient *client, AwsEventType type,void *arg, uint8_t *data, size_t len) {
}

void appendFile(fs::FS &fs, const char * path, const char * message){
    Serial.printf("Appending to file: %s\r\n", path);

    File file = fs.open("/log.txt", FILE_APPEND);
    if(!file){
        Serial.println("- failed to open file for appending");
        return;
    }
    if(file.print(message)){
        Serial.println("- message appended");
    } else {
        Serial.println("- append failed");
    }
    file.close();
}


void setup(){

// Serial port for debugging purposes
Serial.begin(115200);
initWebSocket();



if (!SPIFFS.begin(true)) {
Serial.println("An Error has occurred while mounting SPIFFS");
return;
}

File root = SPIFFS.open("/");

File filelist = root.openNextFile();

while(filelist){

Serial.print("FILE: ");
Serial.println(filelist.name());
filelist = root.openNextFile();
}




// Connect to Wi-Fi network with SSID and password
Serial.print("Setting AP (Access Point)…");
  // Remove the password parameter, if you want the AP (Access Point) to be open
WiFi.softAP(ssid, password);

IPAddress IP = WiFi.softAPIP();
Serial.print("AP IP address: ");
Serial.println(IP);

// Print ESP32 Local IP Address
Serial.println(WiFi.localIP());

// Route for root / web page
server.on("/", HTTP_GET, [](AsyncWebServerRequest *request){
    request->send(SPIFFS, "/index.html", String(), false);
});

//Load PNG
server.on("/logo.png", HTTP_GET, [](AsyncWebServerRequest *request){
    request->send(SPIFFS, "/logo.png", "image/png");
  });

// Route for Home / web page
server.on("/index.html", HTTP_GET, [](AsyncWebServerRequest *request){
    request->send(SPIFFS, "/index.html", String(), false);
});

// Route for download / web page
server.on("/download.html", HTTP_GET, [](AsyncWebServerRequest *request){
    request->send(SPIFFS, "/download.html");
});

// Route for about / web page
server.on("/about.html", HTTP_GET, [](AsyncWebServerRequest *request){
    request->send(SPIFFS, "/about.html");
});
  
  // Route to load style.css file
  server.on("/style.css", HTTP_GET, [](AsyncWebServerRequest *request){
    request->send(SPIFFS, "/style.css", "text/css");
  });

 // Download Log
  server.on("/download", HTTP_GET, [](AsyncWebServerRequest *request){
    request->send(SPIFFS, "/log.txt", String(), true);
  });

// Remove Log
  server.on("/remove", HTTP_GET, [](AsyncWebServerRequest *request){
    //request->send(SPIFFS.remove("/log.txt"));
    SPIFFS.remove("/log.txt");
    appendFile(SPIFFS, "/log.txt", "---------------------------------\r\n");
    appendFile(SPIFFS, "/log.txt", "--  SmithsDash v.0.1  LogFile  --\r\n");
    appendFile(SPIFFS, "/log.txt", "--   by Ennar1991 & bripon76   --\r\n");
    appendFile(SPIFFS, "/log.txt", "---------------------------------\r\n");
    appendFile(SPIFFS, "/log.txt", "");
    request->send(SPIFFS, "/download.html");
  });

  // Start server
  server.begin();
}

char serialBuffer[100];
char serialBufferPosition=0;
void loop(){

ws.cleanupClients();

  if (Serial.available()) {
      serialBuffer[serialBufferPosition]=Serial.read();
      if (serialBuffer[serialBufferPosition]=='\n') {
        //do some kind of action
          ws.textAll(String(serialBuffer)); //this is what we send to the browser
          appendFile(SPIFFS, "/log.txt", (serialBuffer));
        serialBufferPosition=0;
        memset(serialBuffer, 0, sizeof(serialBuffer));
      } else{
        serialBufferPosition++;
      }
  }


  } 
